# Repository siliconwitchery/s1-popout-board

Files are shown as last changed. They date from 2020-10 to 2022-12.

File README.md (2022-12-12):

# S1 Popout Board by Silicon Witchery

A handy breakout board for the [S1 Module](https://www.siliconwitchery.com/module).

**Check out the [S1 SDK](https://github.com/siliconwitchery/s1-sdk) for firmware templates and examples compatible with the S1 Popout.**

**Features:**

- Pre-soldered S1 Module.
- USB-C charging & data.
- JST battery header.
- [QUIIC](https://www.sparkfun.com/qwiic) / [STEMMA QT](https://learn.adafruit.com/introducing-adafruit-stemma-qt) compatible I<sup>2</sup>C port.
- Serial Wire Debug port.
- All GPIO broken out.

Order the S1 Popout Board from [Digi-Key](https://www.digikey.com/en/products/detail/silicon-witchery/S1-POPOUT-BOARD/15926536) 🛍

<br>

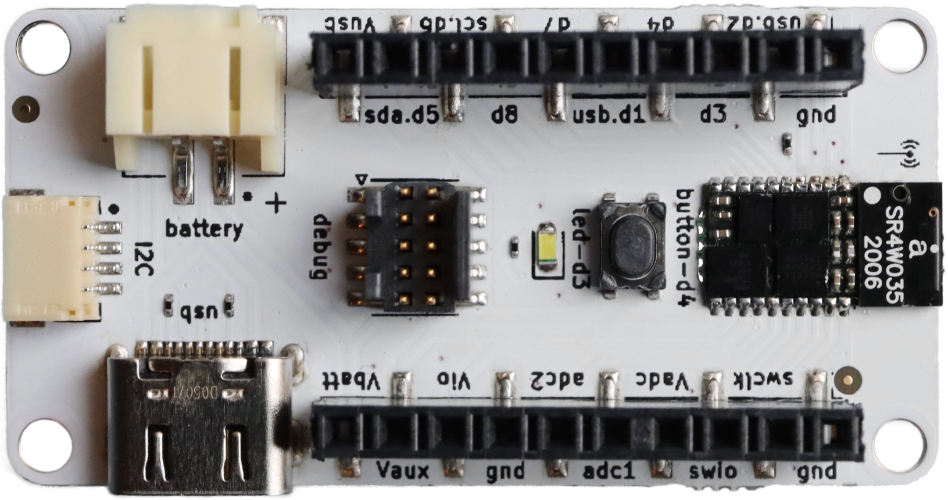
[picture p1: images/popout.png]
S1 Popout Board


<br>

## All in one module
The S1 Popout lets you quickly get started with all kinds of IoT projects. It features our **S1 Module** with:

- **Bluetooth 5.2** based on the Nordic nRF52811.
- **iCE40 FPGA** with 5k LUT & DSP.
- **Battery management** with charging and 3 adjustable voltage rails.
- **32Mb SPI Flash** for storing your FPGA binary and other user data.

## Plug & Play Sensors

I<sup>2</sup>C sensor modules that can be daisy chained using the built in QUIIC / StemmaQT connector. [Sparkfun](https://www.sparkfun.com/qwiic) and [Adafruit](https://learn.adafruit.com/introducing-adafruit-stemma-qt) have tons of modules for popular sensors such as:

- LSM9DS1 9 Axis Accelerometer/Gyro/Magnetometer
- AS7341 10 channel visible & IR light sensor
- PA1010D GPS module
- APDS9960 Proximity Sensor
- ST25DV16K re-programmable NFC tag

<br>

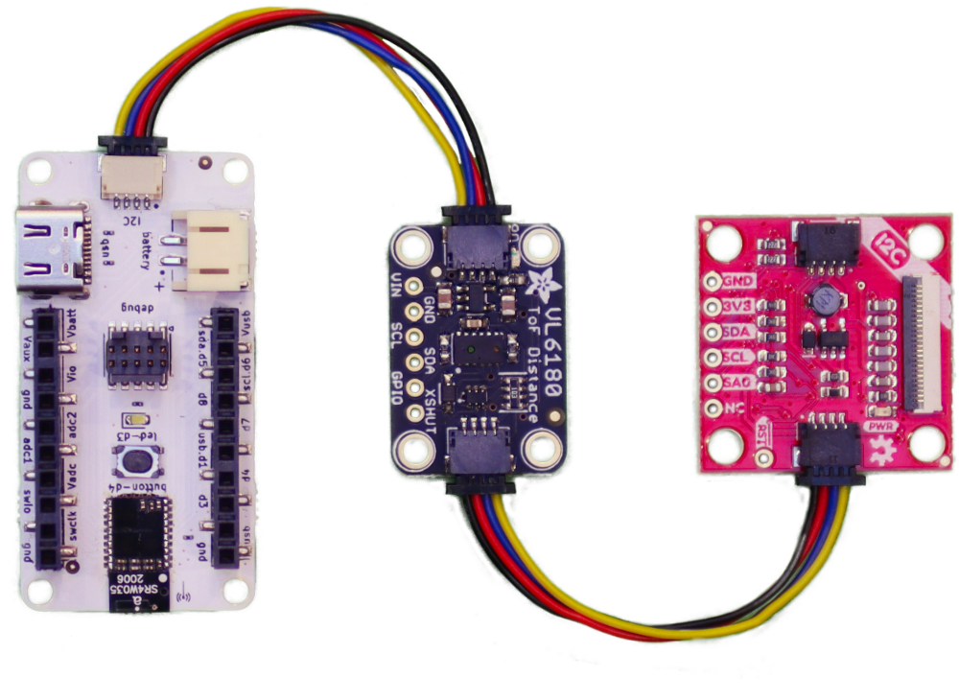
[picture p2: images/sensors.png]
S1 Popout with sensors


<br>

## Battery & USB

You can use any single lithium polymer cell to power the Popout Board, or power it simply from a 5V USB Type C plug.

Connecting the USB cable will also charge any connected battery. By default, the charge rate is low enough that even small cells can safely be charged, however for larger cells, the charge rate should be configured within firmware.

In time we'll also be supporting USB data so you'll be able to talk to the FPGA over USB.

## Licence

Copyright 2022 © Silicon Witchery.

This design is licenced under: [CERN Open Hardware Licence Version 2 - Permissive](https://ohwr.org/cern_ohl_p_v2.pdf).

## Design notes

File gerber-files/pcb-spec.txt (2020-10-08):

PCB Specifications:
---------------------------------------
Copper Layers:      2
Total Dimension:    23.5 x 46 mm
Board Thickness:    1mm
Soldermask Color:   White
Silkscreen Color:   Black
Surface Finish:     ENIG-RoHS
Copper Weight:      1oz
Material:           Standard FR4

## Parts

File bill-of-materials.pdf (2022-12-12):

| | | | Silicon Witchery S1 Popout Board | Bill of Materials | Main BOM - 12 December 2022
Part Name | Part Number | Vendor | Designator | Footprint | Quantity | Primary Supplier | Assembly Notes
White LED | IN-S63AT5UW (https://www.mouser.se/datasheet/2/180/IN-S63AT_Series_V1.1-1488271.pdf) | Inolux | D1 | 0603 SMD | 1 | Mouser: 743-IN-S63AT5UW (https://www.mouser.se/ProductDetail/Inolux/IN-S63AT5UW) | See Front View image for Pin 1 location
USB Type-C Connector | DX07S016JA1R1500 (https://www.mouser.se/datasheet/2/206/JAE_Electronics_01282020_DX07-1729578.pdf) (Drawing) (https://www.jae.com/direct/topics/topics_file_download/topics_id=91780&ext_no=06&index=0&_lang=en&v=2020041313384666992409) | JAE | J1 | SMD | 1 | Mouser: 656-DX07S016JA1R1500 (https://www.mouser.se/ProductDetail/JAE-Electronics/DX07S016JA1R1500) | -
S1 Module | S1-MOD | Silicon Witchery | J3 | SMD | 1 | Silicon Witchery | See Front View image for Pin 1 location
10 Pin 0.1" Female Header | SSM-110-L-SV (https://www.mouser.se/datasheet/2/527/ssm_sm-1317000.pdf) | Samtec | J2, J4 | SMD | 2 | Mouser: 200-SSM110LSV (https://www.mouser.se/ProductDetail/Samtec/SSM-110-L-SV?qs=rU5fayqh%252BE3d0gXuxg0GTg==) | -
2 Pin Connector | S2B-PH-SM4-TB (http://www.farnell.com/datasheets/1699381.pdf) | JST | J5 | SMD | 1 | Farnell: 9492615 (https://se.farnell.com/jst-japan-solderless-terminals/s2b-ph-sm4-tb-lf-sn/connector-header-smt-r-a-2mm-2way/dp/9492615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) | -
10 Pin ARM Debug Connector | FTSH-105-01-F-DV-K (https://datasheet.octopart.com/FTSH-105-01-L-DV-Samtec-datasheet-140825048.pdf) | Samtec | J6 | SMD | 1 | Digikey: SAM8796-ND (https://www.digikey.se/products/en?keywords=SAM8796-ND) | -
4 Pin Connector | SM04B-SRSS-TB(LF)(SN) (http://www.jst-mfg.com/product/pdf/eng/eSH.pdf) | JST | J7 | SMD | 1 | Digikey: 455-1804-1-ND (https://www.digikey.se/products/en?keywords=455-1804-1-ND) | -
Film Resistor 5.1k | RC0201FR-075K1L | Yageo | R1, R2, R4 | 0201 SMD | 3 | Digikey: YAG2741DKR-ND (https://www.digikey.se/product-detail/en/yageo/RC0201FR-075K1L/YAG2741DKR-ND/5282611) | -
Film Resistor 47R | RC0201FR-0747RL | Yageo | R3 | 0201 SMD | 1 | Digikey: YAG2694DKR-ND (https://www.digikey.se/product-detail/en/yageo/RC0201FR-0747RL/YAG2694DKR-ND/5282564) | -
SMD Tactile Button | PTS810 SJM 250 SMTR LFS (https://dznh3ojzb2azq.cloudfront.net/products/Tactile/PTS810/documents/datasheet.pdf) | C&K | SW1 | SMD | 1 | Digikey: CKN10502CT-ND (https://www.digikey.se/product-detail/en/c-k/PTS810-SJM-250-SMTR-LFS/CKN10502CT-ND/4176673) | -
PCB | - | - | - | - | 1 | - | -
Total Unique Parts | - | - | - | - | 10 | - | -
Total Parts | - | - | - | - | 12 | -

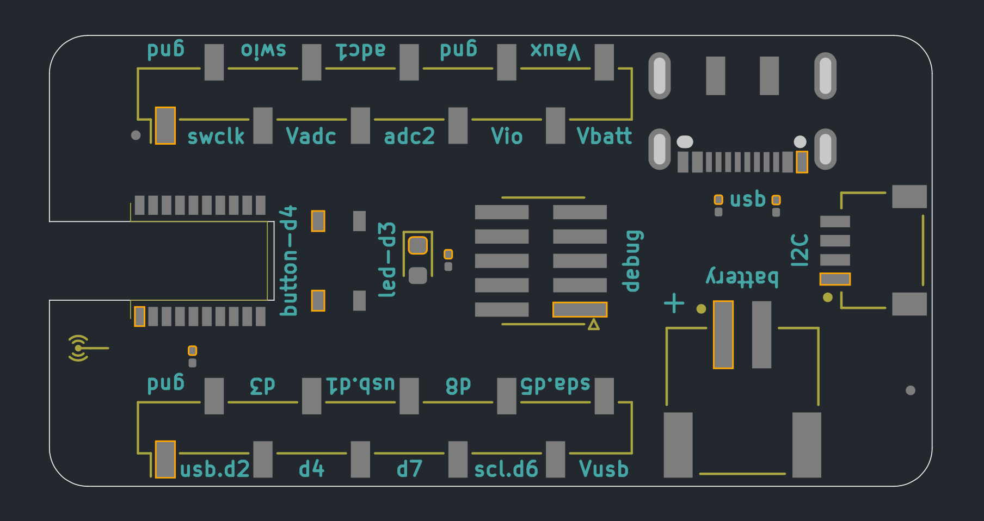
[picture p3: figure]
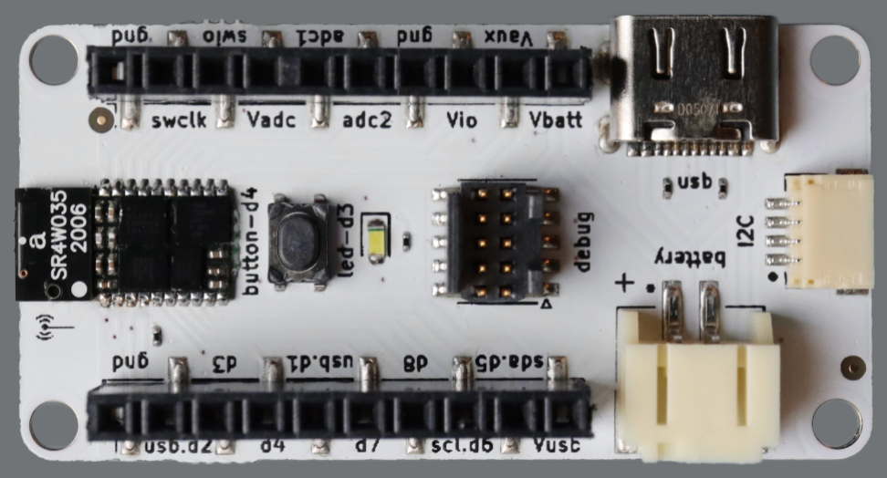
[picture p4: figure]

Front View with Pin 1 highlighted | Reference image

Copyright 2022 © Silicon Witchery.

This design is licensed under CERN OHL-P v2. (https://ohwr.org/cern_ohl_p_v2.pdf)

1

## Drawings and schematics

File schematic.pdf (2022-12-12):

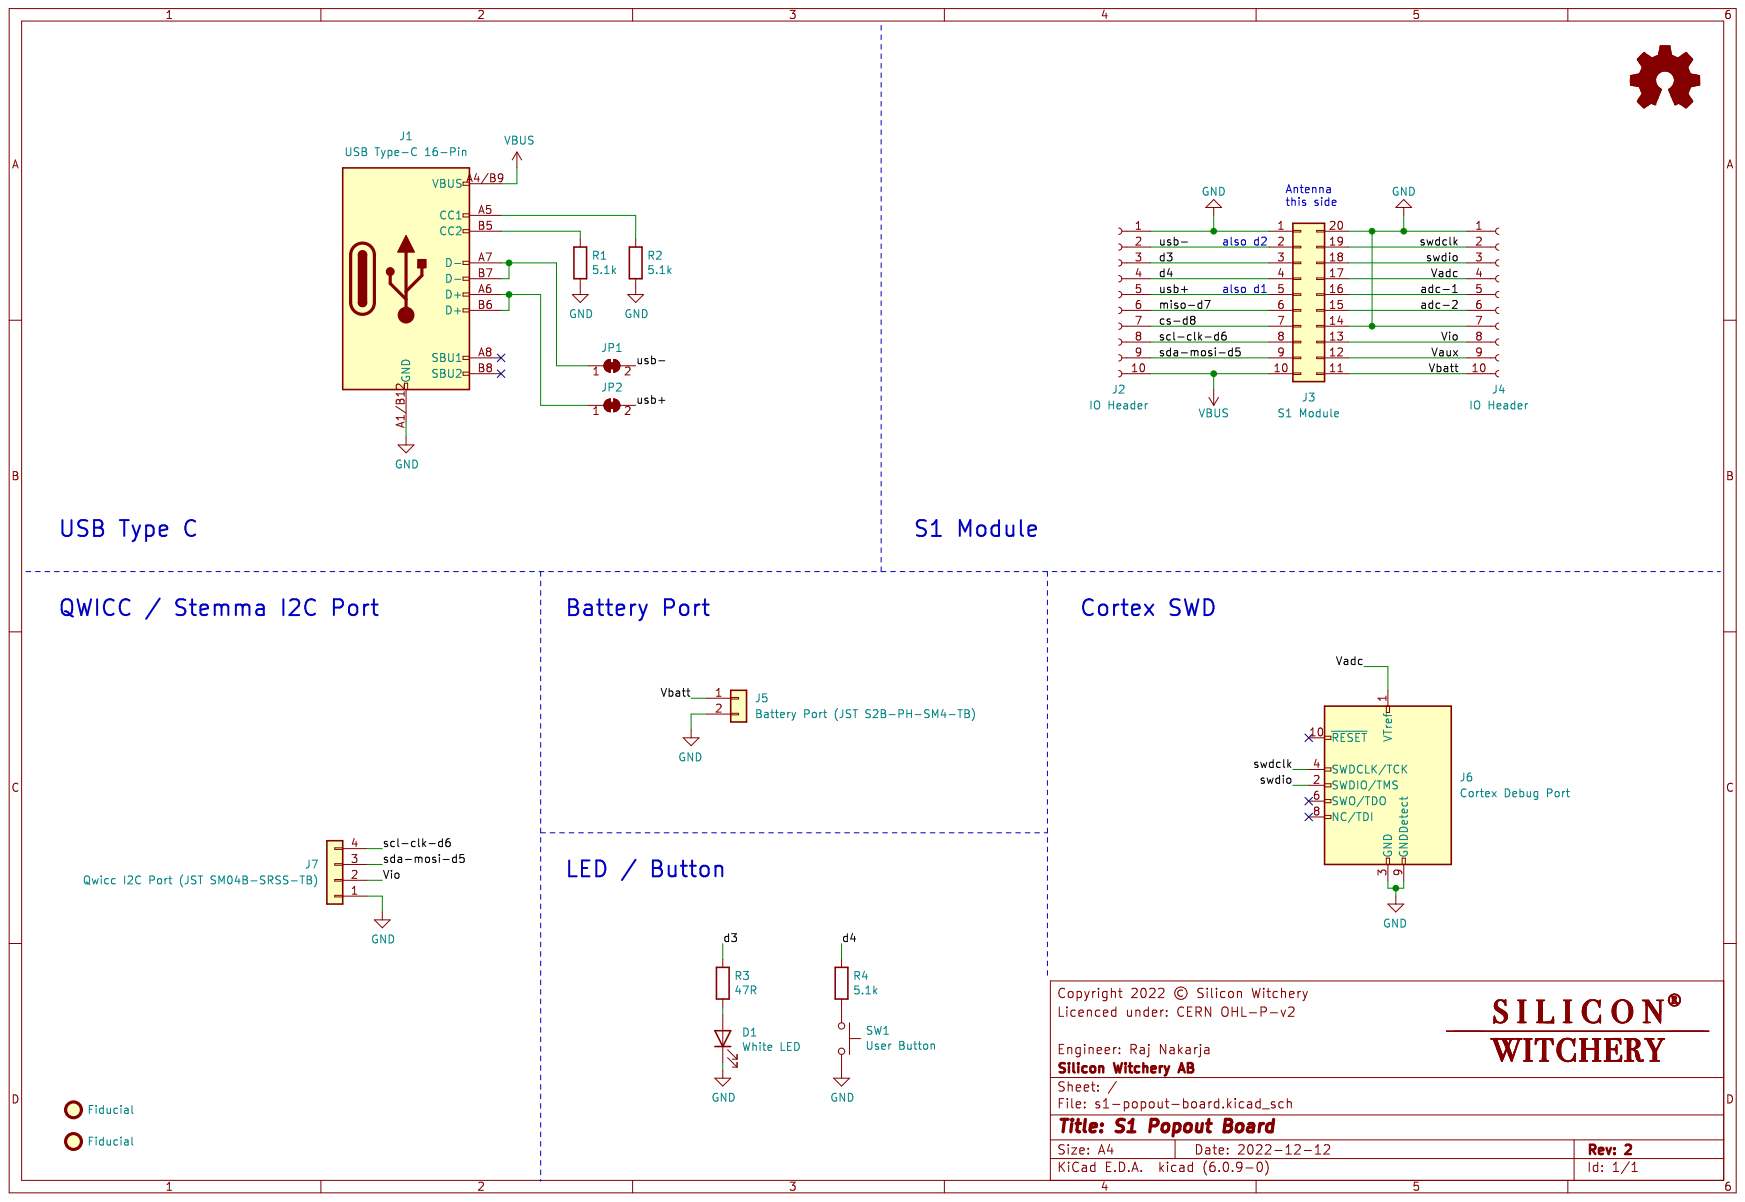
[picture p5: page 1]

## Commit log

2020-09-08 WIP schematic
    [s1-popout-board.kicad_pcb, s1-popout-board.sch]
2020-09-08 Schematic done
    [s1-popout-board.sch]
2020-09-09 PCB design complete - needs checking Updated licence to CC BY 4.0
    [s1-popout-board.kicad_pcb, s1-popout-board.sch]
2020-09-10 BOM complete Changed LED resistor to 47R
    [s1-popout-board.kicad_pcb, s1-popout-board.sch]
2020-09-25 Rev 2 tweaks - Cuttable pads for USB data lines - Smaller module pads - Improved soldermask - Moved vias slightly - exported Gerbers
    [s1-popout-board-B_Cu.gbr, s1-popout-board-B_Mask.gbr, s1-popout-board-B_SilkS.gbr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]
2020-10-07 Matched USB trace Ordered 20 assembled prototypes
    [s1-popout-board-B_Cu.gbr, s1-popout-board-B_Mask.gbr, s1-popout-board-B_SilkS.gbr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]
2020-10-08 Soldermask gap between s1 pins updated to 0.22mm
    [s1-popout-board-B_Cu.gbr, s1-popout-board-B_Mask.gbr, s1-popout-board-B_SilkS.gbr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]
2020-10-08 Date on kicad files updated to reflect r2 order date
    [s1-popout-board.kicad_pcb, s1-popout-board.sch]
2021-01-27 Updated licence and readme
    [s1-popout-board.kicad_pcb, s1-popout-board.sch]
2021-01-27 Exported BOM
2021-01-27 Added PDF schematic
2021-01-28 Updated PnP with all components Updated reference image in BOM
    [s1-popout-board.kicad_pcb]
2021-01-28 Re-exported Gerbers. No changes, just date stamps
    [s1-popout-board-B_Cu.gbr, s1-popout-board-B_Mask.gbr, s1-popout-board-B_SilkS.gbr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]
2021-01-28 Re-exported BOM PDF
2022-12-12 Updated licence
    [s1-popout-board.kicad_pcb, s1-popout-board.kicad_sch]
